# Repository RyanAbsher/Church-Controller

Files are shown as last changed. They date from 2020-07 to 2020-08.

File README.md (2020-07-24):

# Church-Controller
Controller for Church Status Signs

## Introduction
After I finished the [status signs](https://github.com/RyanAbsher/Church-Sign/) for my church, the only way I had to control them was using POST links from a document on my phone.
If I was not attending on a given day, then no one else could use them.
I decided to make a hand-held control, similar to a television remote control, that was simple enough for anyone to pick up and use.

## Hardware
The core of the controller is an ESP-12e module. There are 3 LEDs the match the color options for the status signs, Green, Yellow, and Red.
There are 2 buttons which will be labelled Change and Save. Pressing the Change button will cycle through the 3 LEDs. Once you are on the correct color
press the Save button to send the change to the status signs. All connected signs will change to the same color.
The controller is powered by 3 standard replaceable AA batteries. There is also a low battery indicator LED on the front of the controller.

The hardware was designed using KiCAD. As this was a one-off device, I decided to etch my own 2 sided board instead of ordering from a low cost PCB manufacturer.
This will also allow me to rapidly iterate through designs of there are any mistakes.

## Software
The controller, just like the status signs, is programmed using the Arduino IDE. The status signs publish their Hostname and IP using mDNS. When first powered on, the controller
will search the local network for any such signs. It will perform a connection test with each sign and store the connected devices for future use. If no signs are located, the controller
will use it's LEDs to indicate an error status.

## Case
The case was designed in Fusion 360, and printed in ABS with a standard desktop FDM printer.

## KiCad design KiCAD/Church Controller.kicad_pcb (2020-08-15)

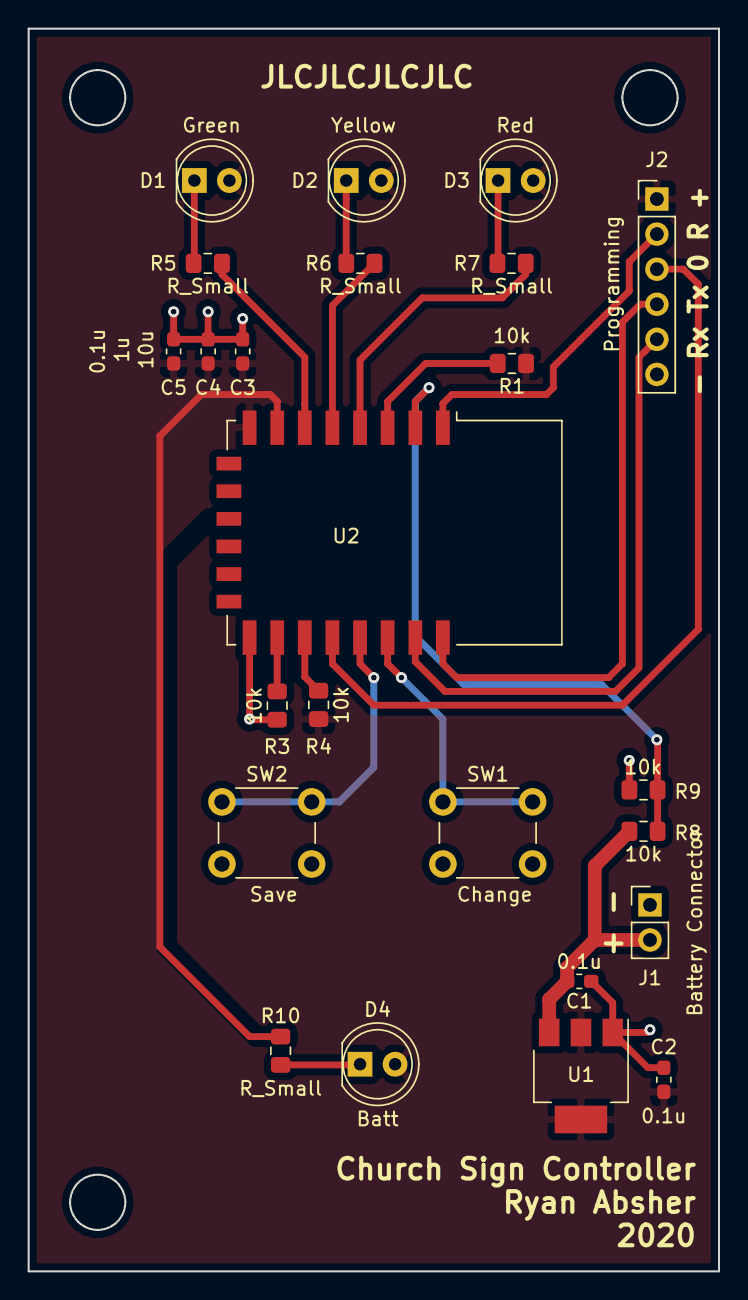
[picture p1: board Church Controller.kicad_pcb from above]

Board: 2 copper layers, 50.0 x 90.0 mm, 24 parts (0 on the bottom side), 21 nets.

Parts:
C1, C2, C5: 0.1u; C_0603_1608Metric_Pad1.05x0.95mm_HandSolder
C3: 10u; C_0603_1608Metric_Pad1.05x0.95mm_HandSolder
C4: 1u; C_0603_1608Metric_Pad1.05x0.95mm_HandSolder
D1: Green; LED_D5.0mm
D2: Yellow; LED_D5.0mm
D3: Red; LED_D5.0mm
D4: Batt; LED_D5.0mm
J1: Battery Connector; PinHeader_1x02_P2.54mm_Vertical
J2: Programming; PinHeader_1x06_P2.54mm_Vertical
R1, R3, R4, R8, R9: 10k; R_0805_2012Metric_Pad1.15x1.40mm_HandSolder
R5, R6, R7, R10: R_Small; R_0805_2012Metric_Pad1.15x1.40mm_HandSolder
SW1: Change; SW_PUSH_6mm_H9.5mm
SW2: Save; SW_PUSH_6mm_H9.5mm
U1: AZ1117-3.3; SOT-223-3_TabPin2
U2: ESP-12E

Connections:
+3V3: C2.2, C3.2, C4.2, C5.2, D1.2, D2.2, D3.2, D4.2, J2.1, R1.1, R4.1, U1.2, U2.8
/BUTTON_CHANGE: SW1.1, U2.20
/BUTTON_SAVE: SW2.1, U2.19
/GPIO0: J2.3, U2.18
/LED_BATT: R10.2, U2.7
/LED_GREEN: R5.2, U2.6
/LED_RED: R7.2, U2.4
/LED_YELLOW: R6.2, U2.5
/Rx: J2.5, U2.21
/Tx: J2.4, U2.22
/~RST: J2.2, U2.1
GND: C1.1, C2.1, C3.1, C4.1, C5.1, J1.1, J2.6, R3.2, R9.2, SW1.2, SW2.2, U1.1, U2.15
unnamed: D1.1, R5.1
unnamed: D2.1, R6.1
unnamed: D3.1, R7.1
unnamed: D4.1, R10.1
unnamed: R1.2, U2.3
unnamed: R3.1, U2.16
unnamed: R4.2, U2.17
unnamed: R8.2, R9.1, U2.2
VCC: C1.2, J1.2, R8.1, U1.3

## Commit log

2020-07-22 Update and Corrections
    Centered some misplaced components, added registration / screw holes to PCB.
    [Church Controller.kicad_pcb]
2020-07-23 Update
    I made the pads for the programming header solid for use with a pogo pin programmer.
    [Church Controller.kicad_pcb]
2020-07-24 Reorganization
    I reorganized the directory structure to allow for the Arduino code.
    [Church Controller.kicad_pcb, Church Controller.sch]
2020-07-29 Update
    Organized schematic
    [Church Controller.sch]
2020-08-07 Update
    Changed programming header, organized silkscreen, generated gerbers, added one missing trace.
    [Church Controller-B.Cu.gbr, Church Controller-B.Mask.gbr, Church Controller-B.Paste.gbr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]
2020-08-07 Updated schematic to match last PCB update
    [Church Controller.sch, _saved_Church Controller.sch]
2020-08-15 Correction
    I didn't realize that you couldn't use GPIO 9 on the ESP-12e. Moved battery LED to GPIO 13.
    [Church Controller.kicad_pcb, Church Controller.sch]
